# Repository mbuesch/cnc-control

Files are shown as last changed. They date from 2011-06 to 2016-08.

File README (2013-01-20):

-------------------------------------
---  CNC-Control
---  Fully Open Source CNC remote control device
------

Copyright (c) 2009-2013 Michael Buesch <m@bues.ch>

--- Integrating CNC-Control into LinuxCNC ---

LinuxCNC 2.5.x or later is required.

Integration into LinuxCNC is easy, because the CNC-Control HAL file is pretty
much selfcontained. Just copy the driver/cnccontrol.hal file to your LinuxCNC
configuration directory. Then modify your .ini file to load the new .hal file.
LinuxCNC can load multiple HAL files. So all that is needed usually is to add
a line like this
HALFILE = cnccontrol.hal
to the end of the [HAL] section of your .ini file. Add the new HALFILE line
below any exitsing HALFILE line.

To install the HAL driver, just go to the "driver" subdirectory and run the
    make
    sudo -i         # become root
    make install
commands. This will install the driver. It will also install a sudo script
to /etc/sudoers.d/zzz-cnccontrol, which is required for the driver to have
access permissions to the USB device.
Note that "sudo" needs to be installed on the system and support for the
/etc/sudoers.d/ directory must available.
If sudo is not installed, install it with
    aptitude install sudo
If your system does not support the sudoers.d directory, you need to manually
adjust your suoders file. In most cases you just need to append the
contents of the zzz-cnccontrol file to your /etc/sudoers file. Use visudo
to edit the sudoers file.

All configuration of the CNC-Control device can be done through the
cnccontrol.hal file. Just look into the file and read the comments.

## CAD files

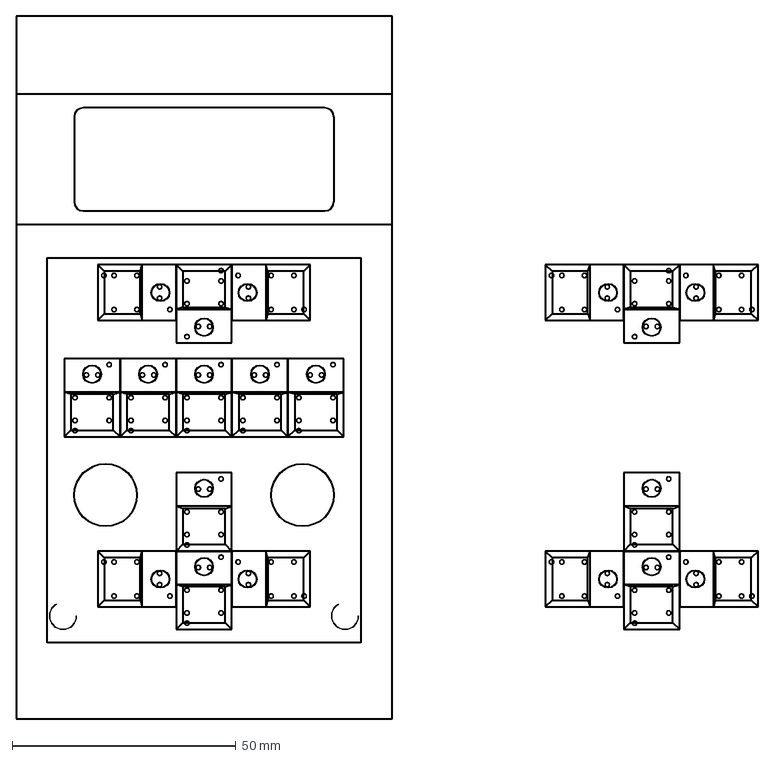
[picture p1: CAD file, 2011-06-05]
schematics/mechanics.dxf
165.8 x 157.0 mm

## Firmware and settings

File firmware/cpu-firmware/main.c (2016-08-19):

/*
 *   CNC-remote-control
 *   CPU
 *
 *   Copyright (C) 2009-2016 Michael Buesch <m@bues.ch>
 *
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
 *   This program is distributed in the hope that it will be useful,
 *   but WITHOUT ANY WARRANTY; without even the implied warranty of
 *   MERCHANTABILITY or FITNESS FOR A PARTICULAR PURPOSE.  See the
 *   GNU General Public License for more details.
 */

#include "main.h"
#include "debug.h"
#include "util.h"
#include "lcd.h"
#include "override.h"
#include "4094.h"
#include "pdiusb.h"
#include "spi.h"

#include <avr/io.h>
#include <avr/interrupt.h>
#include <avr/wdt.h>
#include <avr/pgmspace.h>

#include <string.h>


enum jog_state {
	JOG_STOPPED,			/* Not jogging */
	JOG_RUNNING_POS,		/* Jogging in positive direction */
	JOG_RUNNING_NEG,		/* Jogging in negative direction */
};

/* Left */
enum softkey0_states {
	SK0_AXISPOS,		/* Axis position is displayed. */
	SK0_VELOCITY,		/* Jog velocity is displayed. */

	NR_SK0_STATES,
};

/* Right */
enum softkey1_states {
	SK1_INCREMENT,
	SK1_DEVSTATE,

	NR_SK1_STATES,
};

/* The current state */
struct device_state {
	bool rapid;			/* Rapid-jog on */
	bool incremental;		/* Incremental-jog on */
	fixpt_t increments[6];		/* Possible increments (Modified in IRQ context) */
	uint8_t increment_index;	/* Selected increment for jog (Modified in IRQ context) */
	uint8_t axis;			/* Selected axis (enum axis_id) (Modified in IRQ context) */
	uint16_t axis_enable_mask;	/* Enabled axes (Modified in IRQ context) */

	uint8_t jog;			/* enum jog_state */
	fixpt_t jog_velocity;		/* Jogging velocity */
	jiffies_t next_jog_keepalife;	/* Deadline of next jog keepalife */
	uint8_t fo_feedback_percent;	/* Feed override feedback percentage */
	jiffies_t next_fo_keepalife;	/* Deadline of next feed override keepalife */

	/* The current axis positions.
	 * Updated in IRQ context! */
	fixpt_t positions[NR_AXIS];

	bool spindle_on;		/* Spindle state. Changed in IRQ context. */
	bool spindle_delayed_on;	/* Delayed spindle-on request */
	jiffies_t spindle_change_time;	/* Deadline for spindle-on */
	bool twohand_error;		/* Twohand button error */
	jiffies_t twohand_error_delay;	/* Twohand error delay */

	/* Deferred UI update requests. May be accessed in IRQ context. */
	bool lcd_need_update;
	bool leds_need_update;

	/* Button states. Use get_buttons() to access these fields. */
	bool button_update_required;
	uint16_t buttons;
	int8_t jogwheel;

	/* Softkey states */
	uint8_t softkey[2];

	/* Emergency stop state (read only). */
	bool estop;
};
static struct device_state state;

/* The "external output-port interface" status. */
typedef uint16_t extports_t;
static extports_t extports;


static char get_axis_name(uint8_t axis)
{
	static const char PROGMEM names[] = {
		'X', 'Y', 'Z', 'U', 'V', 'W', 'A', 'B', 'C',
	};

	if (axis >= ARRAY_SIZE(names))
		return '?';
	return (char)pgm_read(&names[axis]);
}

static uint8_t find_next_increment_index(uint8_t start)
{
	uint8_t i, index;

	index = start;
	for (i = 0; i < ARRAY_SIZE(state.increments); i++) {
		index++;
		if (index >= ARRAY_SIZE(state.increments))
			index = 0;
		if (state.increments[index] != INT32_TO_FIXPT(0)) {
			/* Found nonzero. */
			return index;
		}
	}

	return start;
}

static fixpt_t current_increment(void)
{
	fixpt_t ret;
	uint8_t sreg;

	sreg = irq_disable_save();
	ret = state.increments[state.increment_index];
	irq_restore(sreg);

	return ret;
}

static void select_next_axis(void)
{
	uint8_t sreg, axis;

	sreg = irq_disable_save();

	BUG_ON(state.axis_enable_mask == 0);
	axis = state.axis;
	while (1) {
		if (++axis >= NR_AXIS)
			axis = 0;
		if (BIT(axis) & state.axis_enable_mask)
			break;
	}
	state.axis = axis;

	irq_restore(sreg);
}

static void select_previous_axis(void)
{
	uint8_t sreg, axis;

	sreg = irq_disable_save();

	BUG_ON(state.axis_enable_mask == 0);
	axis = state.axis;
	while (1) {
		if (axis == 0)
			axis = NR_AXIS - 1;
		else
			axis--;
		if (BIT(axis) & state.axis_enable_mask)
			break;
	}
	state.axis = axis;

	irq_restore(sreg);
}

void leds_enable(bool enable)
{
	sr4094_outen(enable);
}

static inline void extports_commit(void)
{
	sr4094_put_data(&extports, sizeof(extports));
}

#define _extports_is_set(state, port_id)			\
	(!!((state) & (port_id)))

#define _extports_set(state, port_id)		do {		\
		(state) = (extports_t)((state) | (port_id));	\
	} while (0)

#define _extports_clear(state, port_id)		do {	\
		(state) = (extports_t)((state) & ~(port_id));	\
	} while (0)

static void extports_set(uint16_t extport_id)
{
	if (!_extports_is_set(extports, extport_id)) {
		_extports_set(extports, extport_id);
		extports_commit();
	}
}

static void extports_clear(uint16_t extport_id)
{
	if (_extports_is_set(extports, extport_id)) {
		_extports_clear(extports, extport_id);
		extports_commit();
	}
}

static void extports_init(void)
{
	sr4094_init(&extports, sizeof(extports));
}

static void coprocessor_init(void)
{
	uint8_t result;

	spi_lowlevel_init();

	/* Boot coprocessor application */
	spi_slave_select(1);
	spi_transfer_slowsync(SPI_CONTROL_ENTERAPP);
	spi_slave_select(0);
	long_delay_ms(300);

	spi_slave_select(1);
	spi_transfer_slowsync(SPI_CONTROL_TESTAPP);
	result = spi_transfer_slowsync(SPI_CONTROL_NOP);
	spi_slave_select(0);
	if (result == SPI_RESULT_OK) {
		debug_printf("Coprocessor initialized\n");
	} else {
		debug_printf("Coprocessor init failed (%u)\n", result);
		return;
	}

	GIFR = (1u << SPI_MASTER_TRANSIRQ_INTF);
	GICR |= (1u << SPI_MASTER_TRANSIRQ_INT);
}

ISR(SPI_MASTER_TRANSIRQ_VECT)
{
	ATOMIC_STORE(state.button_update_required, 1);
}

static struct spi_rx_data {
	uint8_t _undefined;
	uint8_t low;
	uint8_t high;
	uint8_t enc;
	uint8_t sum;
} __packed spi_rx_data;

/* Commands sent to the coprocessor (in that order).
 * Must match struct spi_rx_data. */
static const uint8_t PROGMEM spi_tx_data[] = {
	SPI_CONTROL_GETLOW,
	SPI_CONTROL_GETHIGH,
	SPI_CONTROL_GETENC,
	SPI_CONTROL_GETSUM,
	SPI_CONTROL_NOP,
};

static void trigger_button_state_fetching(void)
{
	BUILD_BUG_ON(sizeof(spi_tx_data) != sizeof(spi_rx_data));

	if (!spi_async_running()) {
		ATOMIC_STORE(state.button_update_required, 0);

		spi_async_start(&spi_rx_data, (const void *)spi_tx_data,
				ARRAY_SIZE(spi_tx_data),
				SPI_ASYNC_TXPROGMEM, 1);
	}
}

/* Runs with IRQs disabled */
void spi_async_done(void)
{
	uint8_t expected_sum;

	/* We got all spi_rx_data */

	expected_sum = spi_rx_data.low ^ spi_rx_data.high ^
		       spi_rx_data.enc ^ 0xFF;
	if (unlikely(spi_rx_data.sum != expected_sum)) {
		if (debug_verbose()) {
			debug_printf("SPI: button checksum mismatch: "
				     "was %02X, expected %02X\n",
				     spi_rx_data.sum, expected_sum);
		}
		/* Try again */
		trigger_button_state_fetching();
		return;
	}

	/* Update state. */
	BUG_ON(!irqs_disabled());
	state.buttons = spi_rx_data.low | ((uint16_t)spi_rx_data.high << 8);
	state.jogwheel = (int8_t)(state.jogwheel + (int8_t)spi_rx_data.enc);
}

/* Spindle state may change at any time before or right after this check */
static inline bool spindle_is_on(void)
{
	mb();
	return state.spindle_on;
}

static uint16_t get_buttons(int8_t *_jogwheel)
{
	uint16_t buttons;
	int8_t jogwheel;
	uint8_t sreg;

	sreg = irq_disable_save();

	/* Get the pushbuttons state */
	buttons = state.buttons;
	/* Get the jogwheel state.
	 * One "wheel-click" is equivalent to two state increments.
	 * So we convert the value to "wheel-clicks". */
	jogwheel = state.jogwheel / 2;
	state.jogwheel %= 2;

	irq_restore(sreg);

	*_jogwheel = jogwheel;
	return buttons;
}

static void do_update_lcd(void)
{
	uint8_t sreg;
	uint16_t devflags = get_active_devflags();

	if (ATOMIC_LOAD(state.estop)) {
		lcd_cursor(0, 2);
		lcd_put_str("ESTOP ACTIVE");
		return;
	}

	if (state.twohand_error) {
		lcd_cursor(0, 1);
		lcd_put_str("TWOHAND BUTTON");
		lcd_cursor(1, 4);
		lcd_put_str("RELEASED!");
		return;
	}

	switch (state.softkey[0]) {
	case SK0_AXISPOS: {
		uint8_t axis;
		fixpt_t pos;

		sreg = irq_disable_save();
		axis = state.axis;
		pos = state.positions[axis];
		irq_restore(sreg);

		lcd_put_char(get_axis_name(axis));
		if (devflags & DEVICE_FLG_G53COORDS)
			lcd_put_char('@');
		lcd_printf(FIXPT_FMT3, FIXPT_ARG3(pos));
		break;
	}
	case SK0_VELOCITY: {
		lcd_printf("Vf" FIXPT_FMT0,
			   FIXPT_ARG0(state.jog_velocity));
		break;
	}
	default:
		BUG_ON(1);
	}

	switch (state.softkey[1]) {
	case SK1_INCREMENT:
		lcd_cursor(0, 10);
		lcd_printf("i" FIXPT_FMT3, FIXPT_ARG3(current_increment()));
		break;
	case SK1_DEVSTATE:
		lcd_cursor(0, 11);
		lcd_put_char(state.jog != JOG_STOPPED ? 'J' : ' ');
		lcd_printf("%d%%", state.fo_feedback_percent);
		break;
	default:
		BUG_ON(1);
	}

	/* Left softkey label */
	switch (state.softkey[0]) {
	case SK0_AXISPOS:
		lcd_cursor(1, 0);
		lcd_put_str("Vf");
		break;
	case SK0_VELOCITY:
		lcd_cursor(1, 0);
		lcd_put_str("pos");
		break;
	default:
		BUG_ON(1);
	}

	if (devflags & DEVICE_FLG_ON) {
		lcd_cursor(1, 6);
		lcd_put_str("[ON]");
	} else {
		lcd_cursor(1, 5);
		lcd_put_str("[OFF]");
	}

	/* Right softkey label */
	switch (state.softkey[1]) {
	case SK1_INCREMENT:
		lcd_cursor(1, 11);
		lcd_put_str("state");
		break;
	case SK1_DEVSTATE:
		lcd_cursor(1, 12);
		lcd_put_str("incr");
		break;
	default:
		BUG_ON(1);
	}
}

static void update_lcd(void)
{
	if (debug_verbose())
		debug_printf("Update LCD\n");

	lcd_clear_buffer();
	do_update_lcd();
	lcd_commit();
}

static void update_leds(void)
{
	uint16_t devflags = get_active_devflags();
	extports_t ext = extports;

	if (spindle_is_on())
		_extports_set(ext, EXT_LED_SPINDLE);
	else
		_extports_clear(ext, EXT_LED_SPINDLE);

	if (state.rapid)
		_extports_set(ext, EXT_LED_JOGRAPID);
	else
		_extports_clear(ext, EXT_LED_JOGRAPID);

	if (state.incremental)
		_extports_set(ext, EXT_LED_JOGINC);
	else
		_extports_clear(ext, EXT_LED_JOGINC);

	switch (state.jog) {
	case JOG_STOPPED:
		_extports_clear(ext, EXT_LED_JOGPOS);
		_extports_clear(ext, EXT_LED_JOGNEG);
		break;
	case JOG_RUNNING_POS:
		_extports_set(ext, EXT_LED_JOGPOS);
		_extports_clear(ext, EXT_LED_JOGNEG);
		break;
	case JOG_RUNNING_NEG:
		_extports_clear(ext, EXT_LED_JOGPOS);
		_extports_set(ext, EXT_LED_JOGNEG);
		break;
	default:
		BUG_ON(1);
	}

	if (devflags & DEVICE_FLG_ON)
		_extports_set(ext, EXT_LED_ONOFF);
	else
		_extports_clear(ext, EXT_LED_ONOFF);

	switch (state.softkey[0]) {
	case SK0_AXISPOS:
		if (devflags & DEVICE_FLG_G53COORDS)
			_extports_set(ext, EXT_LED_TOGGLE);
		else
			_extports_clear(ext, EXT_LED_TOGGLE);
		break;
	case SK0_VELOCITY:
		_extports_clear(ext, EXT_LED_TOGGLE);
		break;
	default:
		BUG_ON(1);
	}

	if (extports != ext) {
		extports = ext;
		extports_commit();
	}
}

static void interpret_one_softkey(bool sk, uint8_t index, uint8_t count)
{
	uint8_t sk_state;

	if (!sk)
		return;

	/* Key was pressed */
	sk_state = state.softkey[index];
	sk_state++;
	if (sk_state >= count)
		sk_state = 0;
	state.softkey[index] = sk_state;

	update_userinterface();
}

static void interpret_softkeys(bool sk0, bool sk1)
{
	interpret_one_softkey(sk0, 0, NR_SK0_STATES);
	interpret_one_softkey(sk1, 1, NR_SK1_STATES);
}

static void set_jog_keepalife_deadline(void)
{
	state.next_jog_keepalife = get_jiffies() + msec2jiffies(100);
}

static void jog_incremental(int8_t inc_count)
{
	struct control_interrupt irq = {
		.id		= IRQ_JOG,
		.flags		= IRQ_FLG_DROPPABLE,
	};

	if (!inc_count)
		return;

	irq.jog.increment = current_increment();
	if (irq.jog.increment == INT32_TO_FIXPT(0))
		return;
	if (inc_count < 0)
		irq.jog.increment = fixpt_neg(irq.jog.increment);
	if (abs(inc_count) > 1) {
		irq.jog.increment = fixpt_mult(irq.jog.increment,
					       INT32_TO_FIXPT(abs(inc_count)));
	}
	irq.jog.axis = state.axis;
	irq.jog.flags = state.rapid ? IRQ_JOG_RAPID : 0;
	irq.jog.velocity = state.jog_velocity;

	send_interrupt(&irq, CONTROL_IRQ_SIZE(jog));
}

static void jog_stop(void)
{
	struct control_interrupt irq = {
		.id		= IRQ_JOG,
		.flags		= IRQ_FLG_PRIO,
	};

	if (state.jog == JOG_STOPPED)
		return;

	irq.jog.axis = state.axis;
	irq.jog.flags = IRQ_JOG_CONTINUOUS;
	irq.jog.increment = INT32_TO_FIXPT(0);

	send_interrupt_count(&irq, CONTROL_IRQ_SIZE(jog), 3);

	state.jog = JOG_STOPPED;
}

static void jog(int8_t direction)
{
	struct control_interrupt irq = {
		.id		= IRQ_JOG,
	};

	if (direction) {
		if (state.incremental) {
			jog_stop();
			jog_incremental(direction > 0 ? 1 : -1);
		} else {
			/* Positive or negative jog */
			irq.flags |= IRQ_FLG_DROPPABLE;
			irq.jog.axis = state.axis;
			irq.jog.flags = IRQ_JOG_CONTINUOUS;
			if (state.rapid)
				irq.jog.flags |= IRQ_JOG_RAPID;
			irq.jog.velocity = state.jog_velocity;
			irq.jog.increment = INT32_TO_FIXPT(direction > 0 ? 1 : -1);
			send_interrupt(&irq, CONTROL_IRQ_SIZE(jog));

			state.jog = direction > 0 ? JOG_RUNNING_POS : JOG_RUNNING_NEG;
			set_jog_keepalife_deadline();
		}
	} else
		jog_stop();
	update_userinterface();
}

static void jog_update(void)
{
	switch (state.jog) {
	case JOG_STOPPED:
		jog(0);
		break;
	case JOG_RUNNING_POS:
		jog(1);
		break;
	case JOG_RUNNING_NEG:
		jog(-1);
		break;
	default:
		BUG_ON(1);
	}
}

static void handle_jog_keepalife(void)
{
	struct control_interrupt irq = {
		.id		= IRQ_JOG_KEEPALIFE,
		.flags		= IRQ_FLG_DROPPABLE,
	};

	if (state.jog == JOG_STOPPED)
		return;
	if (!devflag_is_set(DEVICE_FLG_ON))
		return;
	if (time_before(get_jiffies(), state.next_jog_keepalife))
		return;

	send_interrupt_discard_old(&irq, CONTROL_IRQ_SIZE(jog_keepalife));

	set_jog_keepalife_deadline();
}

static void halt_motion(void)
{
	struct control_interrupt irq = {
		.id		= IRQ_HALT,
		.flags		= IRQ_FLG_PRIO,
	};

	send_interrupt_count(&irq, CONTROL_IRQ_SIZE(halt), 3);
}

static void interpret_jogwheel(int8_t jogwheel, bool wheel_pressed)
{
	fixpt_t mult, increment, velocity;
	uint8_t sreg;

	if (wheel_pressed) {
		/* Select bigger INC step. */
		sreg = irq_disable_save();
		state.increment_index = find_next_increment_index(state.increment_index);
		irq_restore(sreg);
		/* Jump to INC state display. */
		state.softkey[1] = SK1_INCREMENT;
		update_userinterface();
		return;
	}

	if (jogwheel) {
		switch (state.softkey[0]) {
		case SK0_AXISPOS:
			jog_incremental(jogwheel);
			break;
		case SK0_VELOCITY:
			if (state.rapid)
				mult = FLOAT_TO_FIXPT(15.0);
			else
				mult = FLOAT_TO_FIXPT(1.0);
			increment = INT32_TO_FIXPT((int32_t)jogwheel);
			increment = fixpt_mult(increment, mult);
			velocity = state.jog_velocity;
			velocity = fixpt_add(velocity, increment);
			if (fixpt_is_neg(velocity))
				velocity = INT32_TO_FIXPT(0);
			if (velocity >= INT32_TO_FIXPT(30000))
				velocity = INT32_TO_FIXPT(30000);
			state.jog_velocity = velocity;
			break;
		default:
			BUG_ON(1);
		}
		update_userinterface();
	}
}

static void turn_spindle_on(void)
{
	struct control_interrupt irq = {
		.id		= IRQ_SPINDLE,
		.flags		= IRQ_FLG_DROPPABLE,
	};

	irq.spindle.state = SPINDLE_CW;
	send_interrupt(&irq, CONTROL_IRQ_SIZE(spindle));
}

static void turn_spindle_off(void)
{
	struct control_interrupt irq = {
		.id		= IRQ_SPINDLE,
		.flags		= IRQ_FLG_PRIO,
	};

	irq.spindle.state = SPINDLE_OFF;
	send_interrupt(&irq, CONTROL_IRQ_SIZE(spindle));
}

static void update_button_led(bool btn_pressed, extports_t ledport)
{
	if (btn_pressed)
		extports_set(ledport);
	else
		extports_clear(ledport);
}

static void set_feed_override_keepalife_deadline(void)
{
	state.next_fo_keepalife = get_jiffies() + msec2jiffies(100);
}

static void interpret_buttons(void)
{
	uint16_t buttons, old_buttons, rising, falling;
	int8_t jogwheel;

	static uint16_t prev_buttons;

#define rising_edge(btn)	(!!(rising & (btn)))
#define falling_edge(btn)	(!!(falling & (btn)))
#define pressed(btn)		(!!(buttons & (btn)))
#define released(btn)		(!pressed(btn))

	buttons = get_buttons(&jogwheel);

	/* Twohand button */
	if (pressed(BTN_TWOHAND)) {
		extports_set(EXT_LED_TWOHAND);
	} else {
		extports_clear(EXT_LED_TWOHAND);
		if (devflag_is_set(DEVICE_FLG_TWOHANDEN)) {
			/* Security switch is not pressed. Report security
			 * related buttons as released. */
			old_buttons = buttons;
			if (!spindle_is_on())
				buttons = (uint16_t)(buttons & ~BTN_SPINDLE);
			buttons = (uint16_t)(buttons & ~(BTN_JOG_POSITIVE |
							 BTN_JOG_NEGATIVE));
			if (old_buttons != buttons || jogwheel) {
				state.twohand_error_delay = get_jiffies() +
						msec2jiffies(200);
				if (!state.twohand_error) {
					state.twohand_error = 1;
					update_userinterface();
				}
			}
			jogwheel = 0;
		}
	}
	if (state.twohand_error &&
	    time_after(get_jiffies(), state.twohand_error_delay)) {
		state.twohand_error = 0;
		update_userinterface();
	}

	/* Edge detection */
	rising = buttons & ~prev_buttons;
	falling = ~buttons & prev_buttons;

	/* on/off button */
	if (rising_edge(BTN_ONOFF)) {
		if (devflag_is_set(DEVICE_FLG_ON)) {
			/* Disable device. */
			modify_devflags(DEVICE_FLG_ON, 0);
		} else {
			/* Enable device. */
			modify_devflags(DEVICE_FLG_ON, DEVICE_FLG_ON);
			set_jog_keepalife_deadline();
			set_feed_override_keepalife_deadline();
		}
	}

	/* Spindle button */
	if (rising_edge(BTN_SPINDLE)) {
		if (spindle_is_on()) {
			turn_spindle_off();
		} else {
			state.spindle_delayed_on = 1;
			state.spindle_change_time = get_jiffies() + msec2jiffies(800);
		}
	}
	if (falling_edge(BTN_SPINDLE))
		state.spindle_delayed_on = 0;

	update_button_led(pressed(BTN_HALT), EXT_LED_HALT);
	if (rising_edge(BTN_HALT))
		halt_motion();

	/* Next axis selection */
	update_button_led(pressed(BTN_AXIS_NEXT), EXT_LED_AXIS_NEXT);
	update_button_led(pressed(BTN_AXIS_PREV), EXT_LED_AXIS_PREV);
	if (rising_edge(BTN_AXIS_NEXT)) {
		jog(0);
		select_next_axis();
		state.softkey[0] = SK0_AXISPOS;
		update_userinterface();
	}

	/* Previous axis selection */
	if (rising_edge(BTN_AXIS_PREV)) {
		jog(0);
		select_previous_axis();
		state.softkey[0] = SK0_AXISPOS;
		update_userinterface();
	}

	/* Rapid-move button */
	if (rising_edge(BTN_JOG_RAPID)) {
		state.rapid = 1;
		jog_update();
		update_userinterface();
	}
	if (falling_edge(BTN_JOG_RAPID)) {
		state.rapid = 0;
		jog_update();
		update_userinterface();
	}

	/* Incremental-button */
	if (rising_edge(BTN_JOG_INC)) {
		jog(0);
		state.incremental = !state.incremental;
		update_userinterface();
	}

	/* Softkeys */
	update_button_led(pressed(BTN_SOFT0), EXT_LED_SK0);
	update_button_led(pressed(BTN_SOFT1), EXT_LED_SK1);
	interpret_softkeys(rising_edge(BTN_SOFT0),
			   rising_edge(BTN_SOFT1));

	/* Jog */
	if (rising_edge(BTN_JOG_POSITIVE))
		jog(1);
	if (rising_edge(BTN_JOG_NEGATIVE))
		jog(-1);
	if (falling_edge(BTN_JOG_NEGATIVE) ||
	    falling_edge(BTN_JOG_POSITIVE))
		jog(0);

	/* Jogwheel. Only if not jogging via buttons. */
	if (state.jog == JOG_STOPPED)
		interpret_jogwheel(jogwheel, rising_edge(BTN_ENCPUSH));

	/* Togglebutton */
	if (rising_edge(BTN_TOGGLE)) {
		switch (state.softkey[0]) {
		case SK0_AXISPOS:
			if (devflag_is_set(DEVICE_FLG_G53COORDS)) {
				modify_devflags(DEVICE_FLG_G53COORDS,
						0);
			} else {
				modify_devflags(DEVICE_FLG_G53COORDS,
						DEVICE_FLG_G53COORDS);
			}
			break;
		case SK0_VELOCITY:
			break;
		default:
			BUG_ON(1);
		}
	}

	prev_buttons = buttons;
#undef rising_edge
#undef falling_edge
#undef pressed
#undef released
}

static void handle_spindle_change_requests(void)
{
	if (state.spindle_delayed_on) {
		if (spindle_is_on()) {
			state.spindle_delayed_on = 0;
			return;
		}
		if (time_after(get_jiffies(), state.spindle_change_time)) {
			turn_spindle_on();
			state.spindle_delayed_on = 0;
		}
	}
}

static void interpret_feed_override(bool force)
{
	struct control_interrupt irq = {
		.id		= IRQ_FEEDOVERRIDE,
		.flags		= IRQ_FLG_DROPPABLE,
	};
	uint8_t fostate;
	static uint8_t prev_state;

	fostate = override_get_pos();

	if (fostate != prev_state ||
	    (devflag_is_set(DEVICE_FLG_ON) &&
	     time_after(get_jiffies(), state.next_fo_keepalife)) ||
	    force) {
		set_feed_override_keepalife_deadline();

		irq.feedoverride.state = fostate;
		send_interrupt_discard_old(&irq,
					   CONTROL_IRQ_SIZE(feedoverride));
	}
	prev_state = fostate;
}

/* Called in IRQ context! */
void set_axis_enable_mask(uint16_t mask)
{
	uint8_t sreg;

	BUG_ON(mask == 0);

	sreg = irq_disable_save();
	if (state.axis_enable_mask != mask) {
		state.axis_enable_mask = mask;
		if (!(BIT(state.axis) & mask))
			state.axis = (uint8_t)(ffs16(mask) - 1u);
		update_userinterface();
	}
	irq_restore(sreg);
}

/* Called in IRQ context! */
void axis_pos_update(uint8_t axis, fixpt_t absolute_pos)
{
	uint8_t sreg;

	BUG_ON(axis >= ARRAY_SIZE(state.positions));

	sreg = irq_disable_save();
	if (state.positions[axis] != absolute_pos) {
		state.positions[axis] = absolute_pos;
		state.lcd_need_update = 1;
	}
	irq_restore(sreg);
}
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
int main(void)
{
	static jiffies_t next_ms_tick;
	jiffies_t j;

	irq_disable();
	wdt_enable(WDTO_500MS);
	debug_init();

	GICR = 0;
	MCUCR = (0 << ISC11) | (0 << ISC10) |
		(1 << ISC01) | (0 << ISC00);

	lcd_init();
	lcd_printf("CNC-Control %u.%u\nInitializing",
		   VERSION_MAJOR, VERSION_MINOR);
	lcd_commit();
	extports_init();
	coprocessor_init();
	override_init();
	pdiusb_init();
	systimer_init();

	reset_device_state();

	irq_enable();
	while (1) {
		j = get_jiffies();
		if (time_after(j, next_ms_tick)) {
			next_ms_tick = j + msec2jiffies(1);
			spi_async_ms_tick();
		}

		if (!ATOMIC_LOAD(state.estop)) {
			if (ATOMIC_LOAD(state.button_update_required))
				trigger_button_state_fetching();
			interpret_buttons();
			interpret_feed_override(0);
			handle_spindle_change_requests();
			handle_jog_keepalife();
		}

		mb();
		if (state.lcd_need_update || state.leds_need_update) {
			bool lcd, leds;

			irq_disable();
			lcd = state.lcd_need_update;
			leds = state.leds_need_update;
			state.lcd_need_update = 0;
			state.leds_need_update = 0;
			irq_enable();

			if (lcd)
				update_lcd();
			if (leds)
				update_leds();
		}

		if (devflag_is_set(DEVICE_FLG_USBLOGMSG))
			handle_debug_ringbuffer();

		wdt_reset();
	}
}

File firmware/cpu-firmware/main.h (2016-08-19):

#ifndef MAIN_H_
#define MAIN_H_

#define VERSION_MAJOR	1
#define VERSION_MINOR	2


#include "util.h"
#include "machine_interface_internal.h"

#include <stdint.h>


/* Timekeeping */
typedef uint16_t	jiffies_t;
typedef int16_t		s_jiffies_t;

/* time_after(a, b) returns true if the time a is after time b. */
#define time_after(a, b)        ((s_jiffies_t)(b) - (s_jiffies_t)(a) < 0)
#define time_before(a, b)       time_after(b, a)

/* Number of jiffies-per-second */
#define JPS			((uint32_t)15625)

/* Convert milliseconds to jiffies. */
#define msec2jiffies(msec)   ((jiffies_t)DIV_ROUND_UP(JPS * (uint32_t)(msec), (uint32_t)1000))

/* Get the jiffies counter */
static inline jiffies_t get_jiffies(void)
{
	/* Our timebase is in Timer1, which is accessed atomically
	 * by atomic 16-bit I/O register access. */
	return (jiffies_t)(TCNT1);
}


/* Pushbuttons */
#define BTN_HALT		(1ul << 0)	/* Motion halt */
#define BTN_SPINDLE		(1ul << 1)	/* Spindle on/off */
#define BTN_AXIS_NEXT		(1ul << 2)	/* Select next axis */
#define BTN_AXIS_PREV		(1ul << 3)	/* Select previous axis */
#define BTN_TOGGLE		(1ul << 4)	/* Generic toggle button */
#define BTN_TWOHAND		(1ul << 5)	/* Twohand security switch */
#define BTN_JOG_POSITIVE	(1ul << 6)	/* JOG + */
#define BTN_JOG_RAPID		(1ul << 7)	/* Rapid JOG */
#define BTN_JOG_NEGATIVE	(1ul << 8)	/* JOG - */
#define BTN_JOG_INC		(1ul << 9)	/* JOG incremental */
#define BTN_SOFT0		(1ul << 10)	/* Softkey 0 */
#define BTN_ONOFF		(1ul << 11)	/* Turn device on/off */
#define BTN_SOFT1		(1ul << 12)	/* Softkey 1 */
#define BTN_ENCPUSH		(1ul << 13)	/* Encoder pushbutton */


/* External output-port interface */
#define EXTPORT(chipnr, portnr)	((1ul << (portnr)) << ((chipnr) * 8))

#define EXT_LED_HALT		EXTPORT(0, 0)
#define EXT_LED_SPINDLE		EXTPORT(0, 1)
#define EXT_LED_AXIS_NEXT	EXTPORT(0, 2)
#define EXT_LED_AXIS_PREV	EXTPORT(0, 3)
#define EXT_LED_TOGGLE		EXTPORT(0, 4)
#define EXT_LED_TWOHAND		EXTPORT(0, 5)
#define EXT_LED_JOGPOS		EXTPORT(0, 6)
#define EXT_LED_JOGRAPID	EXTPORT(0, 7)
#define EXT_LED_JOGNEG		EXTPORT(1, 0)
#define EXT_LED_JOGINC		EXTPORT(1, 1)
#define EXT_LED_SK0		EXTPORT(1, 2)
#define EXT_LED_ONOFF		EXTPORT(1, 3)
#define EXT_LED_SK1		EXTPORT(1, 4)


/* Enable/disable LEDs */
void leds_enable(bool enable);
/* Reset the device */
void reset_device_state(void);
/* Axis mask */
void set_axis_enable_mask(uint16_t mask);
/* Axis manipulation */
void axis_pos_update(uint8_t axis, fixpt_t absolute_pos);
/* Spindle state */
void spindle_state_update(bool on);
/* Feed override feedback */
void feed_override_feedback_update(uint8_t percent);
/* Set the estop feedback state */
void set_estop_state(bool asserted);
/* Sets the increment size at index */
bool set_increment_at_index(uint8_t index, fixpt_t increment);

/* Request an update of the user interface */
void update_userinterface(void);

#endif /* MAIN_H_ */

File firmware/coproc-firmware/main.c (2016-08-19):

/*
 *   CNC-remote-control
 *   Button processor
 *
 *   Copyright (C) 2009-2016 Michael Buesch <m@bues.ch>
 *
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
 *   This program is distributed in the hope that it will be useful,
 *   but WITHOUT ANY WARRANTY; without even the implied warranty of
 *   MERCHANTABILITY or FITNESS FOR A PARTICULAR PURPOSE.  See the
 *   GNU General Public License for more details.
 */

#include "util.h"
#include "spi_interface.h"

#include <avr/io.h>
#include <avr/interrupt.h>
#include <avr/wdt.h>

#include <stdint.h>


typedef uint16_t jiffies_t;


#define BUTTON_DEBOUNCE		msec2jiffies(40)
#define ENC_DEBOUNCE		usec2jiffies(3500)


/* Hardware state of a button */
struct button_hwstate {
	bool state;			/* 1 = pressed, 0 = released */
	bool synchronized;		/* Is synchronized with software state? */
	jiffies_t sync_deadline;	/* Deadline for sync */
};

/* Hardware state of a torque encoder */
struct encoder_hwstate {
	uint8_t gray;			/* The graycode state */
	uint8_t prev_gray;
	bool synchronized;		/* Is synchronized with software state? */
	jiffies_t sync_deadline;	/* Deadline for sync */
};

/* Software state of a torque encoder */
struct encoder_swstate {
	int8_t state;
};

static struct button_hwstate hwstates[14];
static uint16_t swstates;
static struct encoder_hwstate enc_hwstates[1];
static struct encoder_swstate enc_swstates[1];


/* Convert 2bit graycode to binary */
static inline uint8_t gray2bin_2bit(uint8_t graycode)
{
	if (graycode & 2)
		graycode ^= 1;
	return graycode;
}

static void jiffies_init(void)
{
#define JPS			31250 /* jiffies per second */

	/* Initialize the timer to 8M/256=31250 */
	TCNT1 = 0;
	OCR1A = 0;
	TIMSK = 0;
	TCCR1A = 0;
	TCCR1B = (0 << CS10) | (0 << CS11) | (1 << CS12);
}

#define msec2jiffies(ms)	((jiffies_t)((uint32_t)(ms) * JPS / (uint32_t)1000))
#define usec2jiffies(us)	((jiffies_t)((uint32_t)(us) * JPS / (uint32_t)1000000))

#define time_after(a, b)	((int16_t)(b) - (int16_t)(a) < 0)
#define time_before(a, b)	time_after(b, a)

static inline jiffies_t jiffies_get(void)
{
	return TCNT1;
}

static inline void do_button_read(struct button_hwstate *hw,
				  bool state,
				  jiffies_t timestamp)
{
	if (state != hw->state) {
		hw->state = state;
		hw->synchronized = 0;
		hw->sync_deadline = timestamp + BUTTON_DEBOUNCE;
	}
}

static inline void do_encoder_read(struct encoder_hwstate *hw,
				   bool a, bool b,
				   jiffies_t timestamp)
{
	uint8_t gray;

	gray = (uint8_t)((uint8_t)a | ((uint8_t)b << 1u));

	if (gray != hw->gray) {
		hw->gray = gray;
		hw->synchronized = 0;
		hw->sync_deadline = timestamp + ENC_DEBOUNCE;
	}
}

/* Read the hardware states of the buttons */
static void buttons_read(void)
{
	uint8_t b, c, d;
	jiffies_t now;

	b = PINB;
	c = PINC;
	d = PIND;
	now = jiffies_get();

	/* Interpret the buttons */
	do_button_read(&hwstates[0], !(b & (1 << 0)), now);
	do_button_read(&hwstates[1], !(b & (1 << 1)), now);
	do_button_read(&hwstates[2], !(c & (1 << 0)), now);
	do_button_read(&hwstates[3], !(c & (1 << 1)), now);
	do_button_read(&hwstates[4], !(c & (1 << 2)), now);
	do_button_read(&hwstates[5], !(c & (1 << 3)), now);
	do_button_read(&hwstates[6], !(c & (1 << 4)), now);
	do_button_read(&hwstates[7], !(c & (1 << 5)), now);
	do_button_read(&hwstates[8], !(d & (1 << 0)), now);
	do_button_read(&hwstates[9], !(d & (1 << 1)), now);
	do_button_read(&hwstates[10], !(d & (1 << 2)), now);
	do_button_read(&hwstates[11], !(d & (1 << 3)), now);
	do_button_read(&hwstates[12], !(d & (1 << 4)), now);
	do_button_read(&hwstates[13], !(d & (1 << 5)), now);
	BUILD_BUG_ON(ARRAY_SIZE(hwstates) != 14);
	BUILD_BUG_ON(ARRAY_SIZE(hwstates) > sizeof(swstates) * 8);

	/* Interpret the torque encoders */
	do_encoder_read(&enc_hwstates[0], !(d & (1 << 6)), !(d & (1 << 7)), now);
	BUILD_BUG_ON(ARRAY_SIZE(enc_hwstates) != 1);
	BUILD_BUG_ON(ARRAY_SIZE(enc_hwstates) != ARRAY_SIZE(enc_swstates));
}

static void buttons_init(void)
{
	uint8_t i;

	/* Configure inputs and pullups */
	DDRB = (uint8_t)(DDRB & ~0x03u);
	PORTB = (uint8_t)(PORTB | 0x03u);

	DDRC = (uint8_t)(DDRC & ~0x3Fu);
	PORTC = (uint8_t)(PORTC | 0x3Fu);

	DDRD = (uint8_t)(DDRD & ~0xFFu);
	PORTD = (uint8_t)(PORTD | 0xFFu);

	buttons_read();
	for (i = 0; i < ARRAY_SIZE(enc_hwstates); i++)
		enc_hwstates[i].prev_gray = enc_hwstates[i].gray;
}

static void trigger_trans_interrupt(void)
{
	SPI_SLAVE_TRANSIRQ_PORT = (uint8_t)(SPI_SLAVE_TRANSIRQ_PORT &
					    ~(1u << SPI_SLAVE_TRANSIRQ_BIT));
	nop();
	nop();
	SPI_SLAVE_TRANSIRQ_PORT = (uint8_t)(SPI_SLAVE_TRANSIRQ_PORT |
					    (1u << SPI_SLAVE_TRANSIRQ_BIT));
}

static inline uint8_t do_sync_button(struct button_hwstate *hw,
				     uint8_t swstate_bit,
				     jiffies_t now)
{
	bool state;

	if (!hw->synchronized) {
		if (time_after(now, hw->sync_deadline)) {
			state = hw->state;
			irq_disable();
			if (state)
				swstates |= (1u << swstate_bit);
			else
				swstates &= ~(1u << swstate_bit);
			irq_enable();
			hw->synchronized = 1;

			return 1;
		}
	}

	return 0;
}

static inline uint8_t do_sync_encoder(struct encoder_hwstate *hw,
				      struct encoder_swstate *sw,
				      jiffies_t now)
{
	uint8_t cur, prev;

	if (!hw->synchronized) {
		if (time_after(now, hw->sync_deadline)) {
			cur = gray2bin_2bit(hw->gray);
			prev = gray2bin_2bit(hw->prev_gray);
			hw->prev_gray = hw->gray;
			hw->synchronized = 1;
			if (cur == ((prev + 1) & 3)) {
				irq_disable();
				sw->state--;
				irq_enable();

				return 1;
			}
			if (cur == ((prev - 1) & 3)) {
				irq_disable();
				sw->state++;
				irq_enable();

				return 1;
			}
		}
	}

	return 0;
}

/* Synchronize the software state of the buttons */
static void buttons_synchronize(void)
{
	uint8_t i, one_state_changed = 0;
	jiffies_t now;

	now = jiffies_get();

	/* Sync buttons */
	for (i = 0; i < ARRAY_SIZE(hwstates); i++) {
		one_state_changed |= do_sync_button(&hwstates[i], i,
						    now);
	}

	/* Sync encoders */
	for (i = 0; i < ARRAY_SIZE(enc_hwstates); i++) {
		one_state_changed |= do_sync_encoder(&enc_hwstates[i],
						     &enc_swstates[i],
						     now);
	}

	if (one_state_changed)
		trigger_trans_interrupt();
}

static noreturn void enter_bootloader(void)
{
	irq_disable();
	wdt_reset();

	/* Jump to bootloader code */
	__asm__ __volatile__(
	"ijmp\n"
	: /* None */
	: [_Z]		"z" (BOOT_OFFSET / 2)
	);
	unreachable();
}
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

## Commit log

2011-06-05 Fix CPU firmware build
    [spi.h]
2011-06-16 Implement jog-keepalife in the host driver
2011-06-16 Obey USB high-power rules
2011-06-17 Some interrupt queue fixes
    [machine_interface.c, machine_interface.h, main.c]
2011-06-20 Send axis mask to device
2011-06-20 Some driver cleanups
2011-06-20 Fix control message flags passing
    [cnccontrol_driver.py]
2011-06-21 Driver boot fixes
2011-06-21 Fix reply message header flags passing
    [cnccontrol_driver.py]
2011-06-22 Optimize device flag fetching
2011-06-23 Add support for more axes
    [cnccontrol.hal]
2011-06-24 Some async SPI fixes
    [main.c, spi.c]
2011-06-24 Minor jogging driver fixes
2011-06-24 Renice HAL driver
2011-06-25 Show warning if keepalife timer expires
2011-06-25 Fix control message sequence number
    [cnccontrol_driver.py]
2011-06-25 Reset IRQ sequence number on USB reset
    [machine_interface.c]
2011-06-28 Add debugging knob to .hal file
    [cnccontrol.hal]
2011-06-28 Add flag to enable/disable USB log messages
    [cnccontrol.hal]
2011-07-14 pdiusb: Some EP select fixes
    [pdiusb.c]
2011-07-15 pdiusb: Some EP stalling fixes
    [pdiusb.c, pdiusb.h, usb.h]
2011-07-17 driver: Improve exception handling.
2011-07-28 Fix oveflow flag handling
    [machine_interface.c]
2011-07-29 Remove seqno checking.
    It doesn't work with IRQ discarding.
    [cnccontrol_driver.py]
2011-07-30 Send important interrupt three times
2011-07-30 Implement spindle start/stop using bitpoke
2011-07-30 Add schematics in .ps format
2011-09-08 Add sudo wrapper to run driver as root
2011-09-08 driver: Fix device connect detection
    [cnccontrol_driver.py]
2011-09-08 Install driver with python distutils
2011-09-10 driver: enable renicing
2011-09-11 driver: Improve USB exception handling
2011-09-11 driver: Cleanup unplug handling
2011-09-11 driver: Add performance debugging
    [cnccontrol.hal]
2011-09-11 driver: Honor machine mode for spindle and jog control
    [cnccontrol.hal]
2011-09-11 Show coordinates in user coords
    [cnccontrol.hal]
2011-09-11 hal driver: Add periodic ping to event handler.
2011-09-12 Add increment value checks
    [cnccontrol.hal]
2011-09-12 Probe for sudo -n option before usage
2011-09-12 hal driver: Cancel JOG motion on device turn-off
2011-09-13 Convert HAL driver to OOP
2012-09-10 Fix compile on newer avr-libc
    [bootloader.c, lcd.h, main.c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]
2012-10-05 cpu-firmware: Defer PDIUSB interrupt handling to mainloop
2013-01-19 Twohand button fixes
2013-01-20 Fix bootloader flash writing
    [bootloader.c]
2016-08-13 coproc: Fix compiler warnings
    [bootloader.c, main.c]
2016-08-13 cpu: Fix compiler warnings
    [bootloader.c, lcd.h, machine_interface.c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]
2016-08-17 usb: Add zero length frame support to app layer tx polling
2016-08-17 pdiusb: Handle interrupt in the interrupt handler
    This removes the work handler. It is too slow.
    [bootloader.c, main.c, pdiusb.c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]
2016-08-17 driver: Improve robustness
2016-08-19 usb: Fix incorrect handling of app layer tx polling
    The UNHANDLED special case must not be assigned to the length variable.
2016-08-19 driver: Enforce Python2
2016-08-19 spi: Make struct static
2016-08-19 Reset deadlines on device enable
    [main.c]
2023-06-03 More 2 to 3 fixes
    [cnccontrol_driver.py]
2023-06-03 Rename emc -> linuxcnc
    [cnccontrol.hal]
2023-06-03 Update LinuxCNC
    [cnccontrol.hal]

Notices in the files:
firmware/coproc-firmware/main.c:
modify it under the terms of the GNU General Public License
